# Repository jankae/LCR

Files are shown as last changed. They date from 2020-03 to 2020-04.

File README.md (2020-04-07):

# LCR Meter

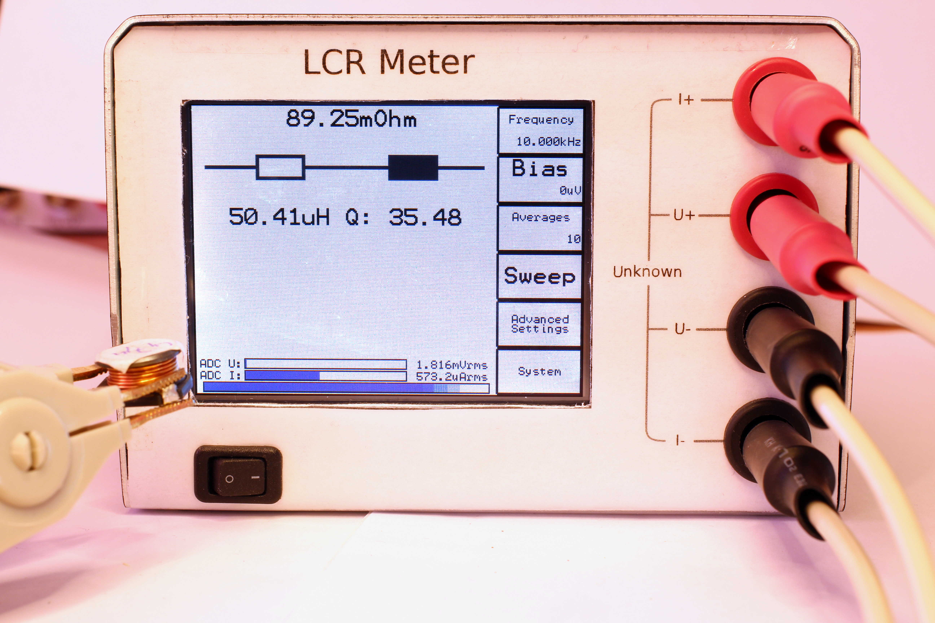
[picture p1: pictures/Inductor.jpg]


### Key specifications
* Measurement frequency: 100Hz-200kHz
* Usable impedance range: 20mOhm-1MOhm (measurements above and below this range are possible but due to very low ADC values, the reported phase will be quite noisy)
### Some useful features
* Optionally apply DC bias voltage up to 10V (measure effective capacitance of MLCCs)
* Autoranging
* Open/Short calibration (lead compensation)
* Fully configurable sweep, showing up to two parameters across frequency:
  * Impedance
  * Phase
  * Capacitance
  * Inductance
  * ESR
  * Quality factor
##### Example of a sweep, showing the self-resonant frequency of a capacitor at approximately 5.5kHz
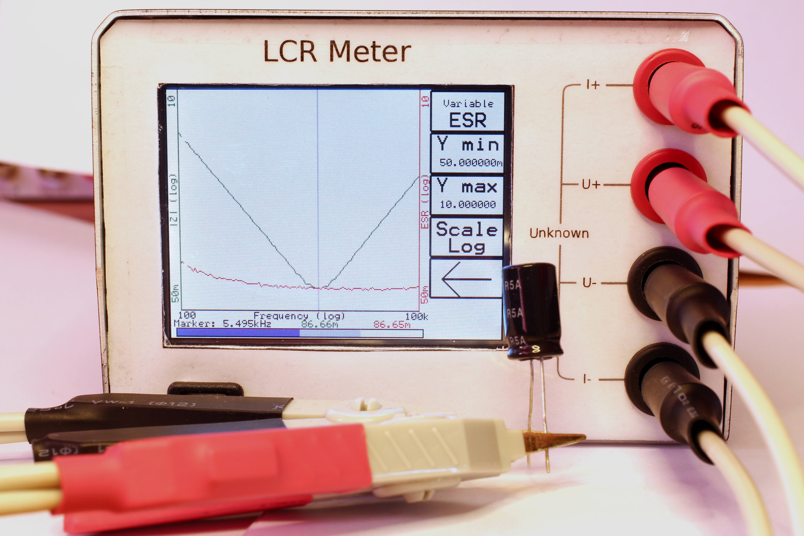
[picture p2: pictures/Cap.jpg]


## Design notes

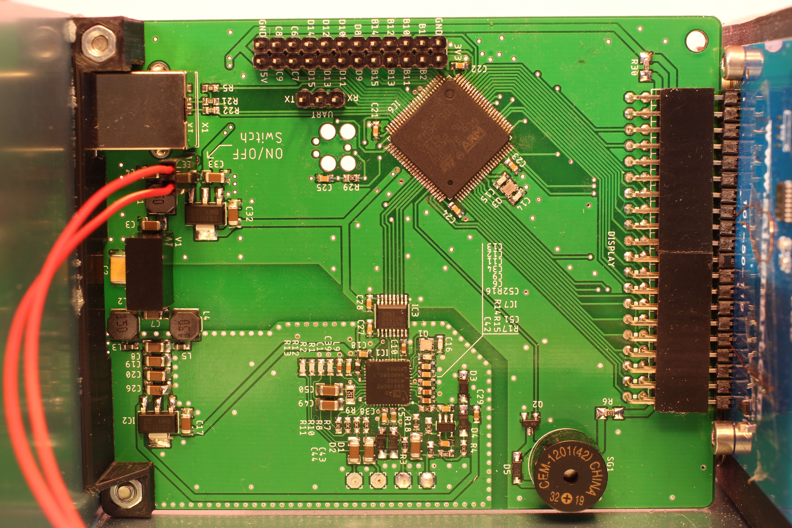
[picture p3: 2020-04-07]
pictures/PCB.jpg

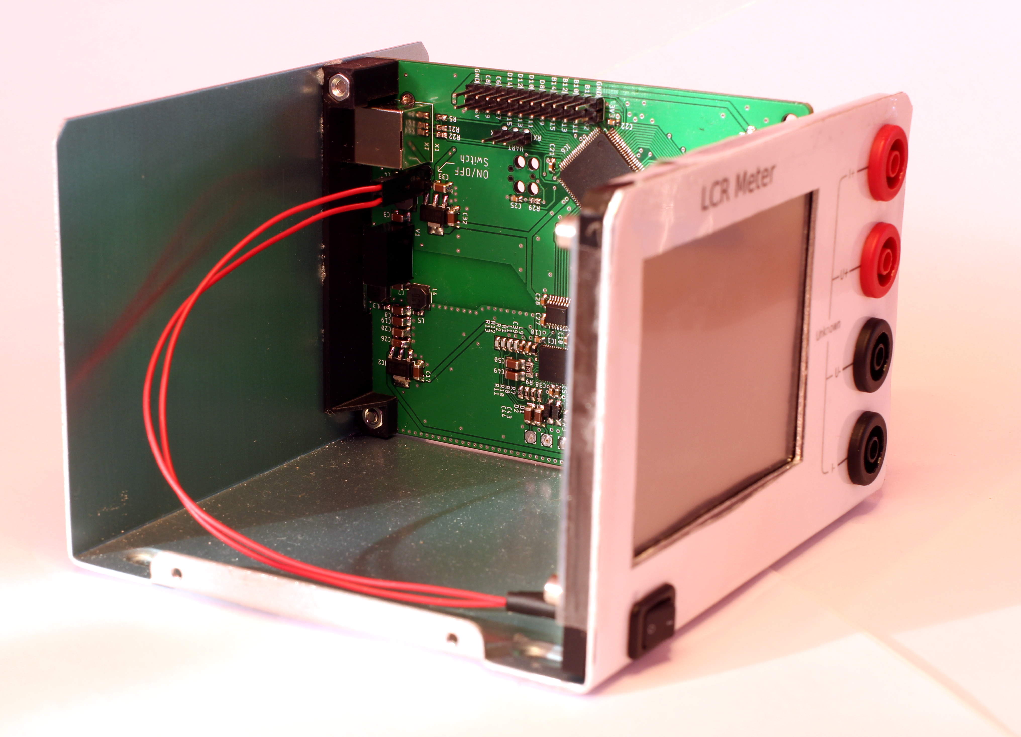
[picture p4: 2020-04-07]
pictures/LCR_left.jpg

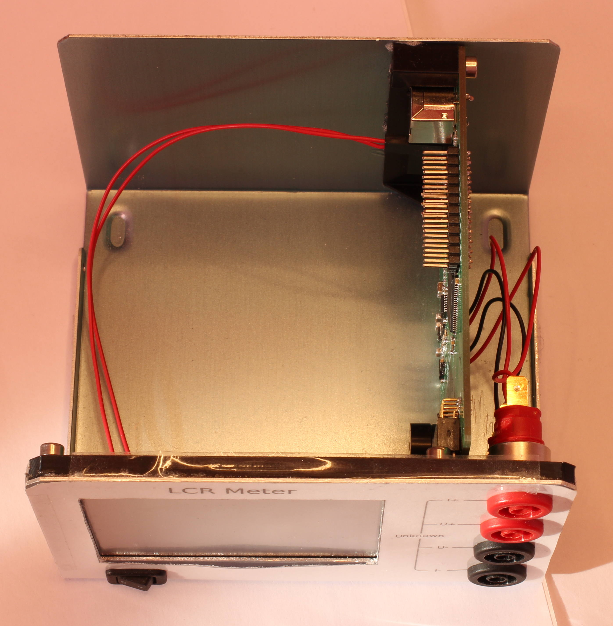
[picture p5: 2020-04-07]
pictures/Top.jpg

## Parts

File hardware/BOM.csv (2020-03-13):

Qty | Value | Device | Package | Parts | Mouser Link
4 |  | 2,54/1,1 | 2,54/1,1 | I+, I-, U+, U- | DNP
1 |  | PINHD-1X2 | 1X02 | JP1 | available
1 |  | PINHD-1X3 | 1X03 | UART | available
1 |  | PINHD-2X12 | 2X12 | JP2 | available
1 |  | TC2030-MCP | TC2030-MCP | J1 | DNP
2 | 10 | R-EU_R0603 | R0603 | R3, R18 | available
1 | 100 | R-EU_R0603 | R0603 | R17 | available
1 | 100k | R-EU_R0603 | R0603 | R4 | available
14 | 100n | C-EUC0603K | C0603K | C11, C18, C21, C22, C23, C24, C25, C27, C28, C34, C38, C39, C51, C52 | available
7 | 10k | R-EU_R0603 | R0603 | R7, R8, R10, R11, R14, R16, R29 | available
2 | 10p | C-EUC0603K | C0603K | C13, C16 | CC0603JRNPO9BN100
5 | 10u | C-EUC1206K | C1206K | C42, C43, C44, C49, C50 | TMK316BJ106ML-T
5 | 10u/16V | C-EUC1206K | C1206K | C3, C4, C17, C32, C33 | TMK316BJ106ML-T
5 | 10u/25V | C-EUC1206K | C1206K | C7, C8, C19, C20, C26 | TMK316BJ106ML-T
2 | 12p | C-EUC0603K | C0603K | C14, C15 | available
4 | 1M | R-EU_R0603 | R0603 | R1, R2, R12, R13 | available
1 | 1k 0.01% 2ppm | R-EU_M0805 | M0805 | R9 | RG2012L-102-L-T05
1 | 1k5 | R-EU_R0603 | R0603 | R5 | available
2 | 1u | C-EUC0603K | C0603K | C12, C29 | available
2 | 22 | R-EU_R0603 | R0603 | R21, R22 | available
2 | 27 | R-EU_R1206 | R1206 | R6, R30 | available
1 | 39k | R-EU_R0603 | R0603 | R15 | available
1 | 4148 | DIODE-SOD123 | SOD123 | D5 | MMSD4148T3G
4 | 470n | C-EUC0603K | C0603K | C1, C6, C9, C10 | CC0603ZRY5V7BB474
1 | 470p/3kV | C-EUC1812 | C1812 | C2 | 885352211001
1 | 4u7 | C-EUC0603K | C0603K | C5 | EMK107ABJ475MA-T
1 | AD5941 | AD5941 | QFN50P700X700X80-49T510N | IC1 | AD5941BCPZ-RL7
4 | BAS116 | DIODE-SOD123 | SOD123 | D1, D2, D3, D4 | BAS116GWJ
1 | BSS123 | BSS123 | SOT23 | Q2 | available
1 | CEM-1203(42) | F/QMBIII | F/QMBIII | SG1 | CEM-1201(42)
2 | FA-128 | FA-128 | FA-128 | Q1, Q3 | FA-128 32.0000MF10Z-AJ5 | FA-128 16.0000MF10Z-AC0
3 | Ferrite | INDUCTOR0603 | R0603 | L3, L5, L9 | available
1 | MINI-USB_SHIELD4P-85-32004-00X | MINI-USB_SHIELD4P-85-32004-00X | 85-32004-00X | X1 | SS-52300-001
1 | OPA237N | OPA237N | SOT23-5 | IC7 | OPA237NA/3K
1 | SAINSMART_TFT_3.2V | SAINSMART_TFT_3.2V | SAINSMART_ANGLED | DISPLAY | available
1 | SI8651EB-B-IU | SI8651EB-B-IU | SOP63P600X175-16N | IC3 | SI8651EB-B-IU
3 | SRN5020TA-100M | SRN5040 | SRN5040 | L1, L2, L4 | SRN5020TA-150M
1 | STM32F303VCT | STM32F303VCT | LQFP100 | IC6 | STM32F303VET6
1 | TBA-1 0512 | TME0505S | TME | V1 | TBA 1-0512
2 | VREG-TS1117CW-3V3 | VREG-TS1117CW-3V3 | SOT223 | IC2, IC9 | TS1117BCW33 RPG

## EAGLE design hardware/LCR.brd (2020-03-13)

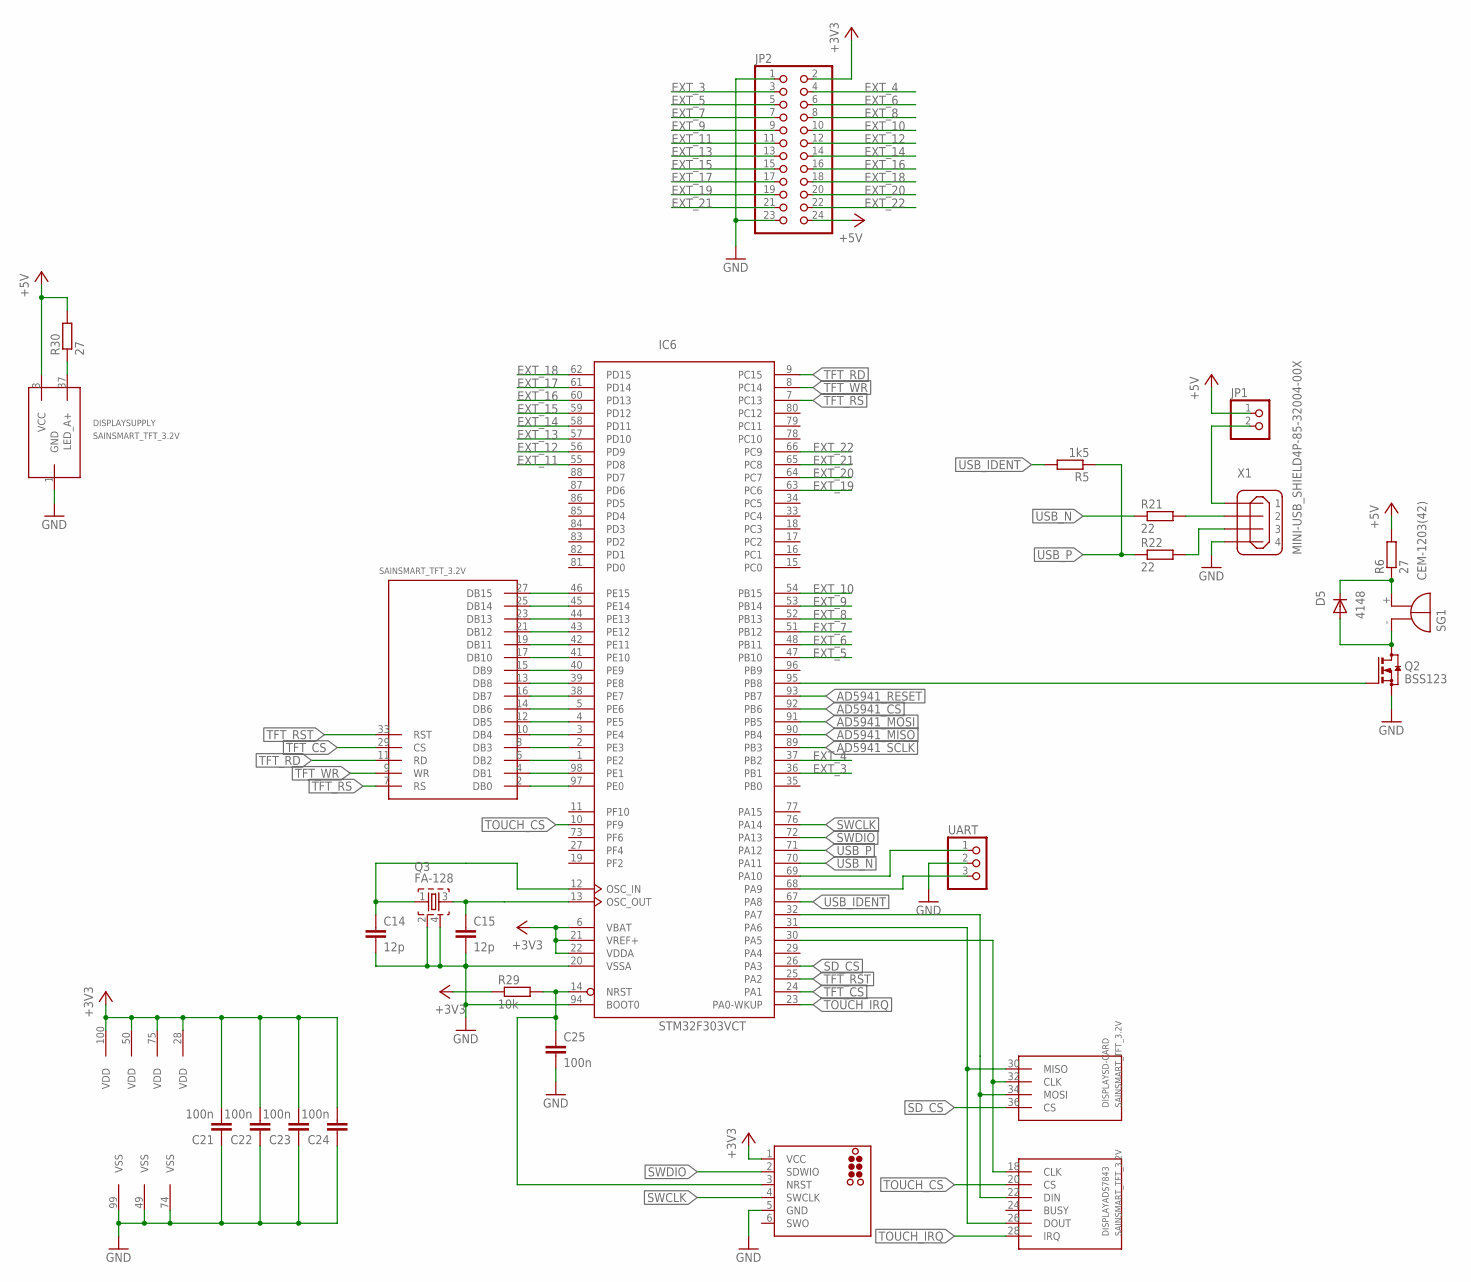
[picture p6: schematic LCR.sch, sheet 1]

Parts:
C14, C15: 12p; C0603K
C21, C22, C23, C24, C25: 100n; C0603K
D5: 4148; SOD123
DISPLAY: SAINSMART_TFT_3.2V; SAINSMART_ANGLED
IC6: STM32F303VCT; LQFP100
J1: TC2030-MCP
JP1: PINHD-1X2; 1X02
JP2: PINHD-2X12; 2X12
Q2: BSS123; SOT23
Q3: FA-128
R5: 1k5; R0603
R6, R30: 27; R1206
R21, R22: 22; R0603
R29: 10k; R0603
SG1: CEM-1203(42); F/QMBIII
UART: PINHD-1X3; 1X03
X1: MINI-USB_SHIELD4P-85-32004-00X; 85-32004-00X

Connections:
+3V3: C21.2, C22.2, C23.2, C24.2, IC6.6 (VBAT), IC6.21 (VREF+), IC6.22 (VDDA), IC6.28 (VDD), IC6.50 (VDD), IC6.75 (VDD), IC6.100 (VDD), J1.1 (VCC), JP2.2, R29.1; also elsewhere on the board
+5V: DISPLAY.3 (VCC), JP1.1, JP2.24, R6.2, R30.2; also elsewhere on the board
AD5941_CS: IC6.92 (PB6); also elsewhere on the board
AD5941_MISO: IC6.90 (PB4); also elsewhere on the board
AD5941_MOSI: IC6.91 (PB5); also elsewhere on the board
AD5941_RESET: IC6.93 (PB7); also elsewhere on the board
AD5941_SCLK: IC6.89 (PB3); also elsewhere on the board
EXT_3: IC6.36 (PB1), JP2.3
EXT_4: IC6.37 (PB2), JP2.4
EXT_5: IC6.47 (PB10), JP2.5
EXT_6: IC6.48 (PB11), JP2.6
EXT_7: IC6.51 (PB12), JP2.7
EXT_8: IC6.52 (PB13), JP2.8
EXT_9: IC6.53 (PB14), JP2.9
EXT_10: IC6.54 (PB15), JP2.10
EXT_11: IC6.55 (PD8), JP2.11
EXT_12: IC6.56 (PD9), JP2.12
EXT_13: IC6.57 (PD10), JP2.13
EXT_14: IC6.58 (PD11), JP2.14
EXT_15: IC6.59 (PD12), JP2.15
EXT_16: IC6.60 (PD13), JP2.16
EXT_17: IC6.61 (PD14), JP2.17
EXT_18: IC6.62 (PD15), JP2.18
EXT_19: IC6.63 (PC6), JP2.19
EXT_20: IC6.64 (PC7), JP2.20
EXT_21: IC6.65 (PC8), JP2.21
EXT_22: IC6.66 (PC9), JP2.22
GND: C14.2, C15.2, C21.1, C22.1, C23.1, C24.1, C25.2, DISPLAY.1 (GND), IC6.20 (VSSA), IC6.49 (VSS), IC6.74 (VSS), IC6.94 (BOOT0), IC6.99 (VSS), J1.5 (GND), JP2.1, JP2.23, Q2.2 (S), Q3.2, Q3.4, UART.2, X1.4; also elsewhere on the board
unnamed: IC6.95 (PB8), Q2.1 (G)
unnamed: DISPLAY.2 (DB0), IC6.97 (PE0)
unnamed: DISPLAY.4 (DB1), IC6.98 (PE1)
unnamed: DISPLAY.6 (DB2), IC6.1 (PE2)
unnamed: DISPLAY.8 (DB3), IC6.2 (PE3)
unnamed: DISPLAY.22 (DIN), DISPLAY.34 (MOSI), IC6.32 (PA7)
unnamed: DISPLAY.10 (DB4), IC6.3 (PE4)
unnamed: DISPLAY.12 (DB5), IC6.4 (PE5)
unnamed: DISPLAY.14 (DB6), IC6.5 (PE6)
unnamed: DISPLAY.16 (DB7), IC6.38 (PE7)
unnamed: DISPLAY.26 (DOUT), DISPLAY.30 (MISO), IC6.31 (PA6)
unnamed: DISPLAY.18 (CLK), DISPLAY.32 (CLK), IC6.30 (PA5)
unnamed: C14.1, IC6.12 (OSC_IN), Q3.1
unnamed: C15.1, IC6.13 (OSC_OUT), Q3.3
unnamed: R21.2, X1.2
unnamed: R22.2, X1.3
unnamed: C25.1, IC6.14 (NRST), J1.3 (NRST), R29.2
unnamed: DISPLAY.37 (LED_A+), R30.1
unnamed: DISPLAY.13 (DB8), IC6.39 (PE8)
unnamed: DISPLAY.15 (DB9), IC6.40 (PE9)
unnamed: DISPLAY.17 (DB10), IC6.41 (PE10)
unnamed: DISPLAY.19 (DB11), IC6.42 (PE11)
unnamed: JP1.2, X1.1
unnamed: D5.C, R6.1, SG1.+ (-)
unnamed: DISPLAY.21 (DB12), IC6.43 (PE12)
unnamed: DISPLAY.23 (DB13), IC6.44 (PE13)
unnamed: DISPLAY.25 (DB14), IC6.45 (PE14)
unnamed: DISPLAY.27 (DB15), IC6.46 (PE15)
unnamed: D5.A, Q2.3 (D), SG1.- (+)
RX: IC6.69 (PA10), UART.1
SD_CS: DISPLAY.36 (CS), IC6.26 (PA3)
SWCLK: IC6.76 (PA14), J1.4 (SWCLK)
SWDIO: IC6.72 (PA13), J1.2 (SDWIO)
TFT_CS: DISPLAY.29 (CS), IC6.24 (PA1)
TFT_RD: DISPLAY.11 (RD), IC6.9 (PC15)
TFT_RS: DISPLAY.7 (RS), IC6.7 (PC13)
TFT_RST: DISPLAY.33 (RST), IC6.25 (PA2)
TFT_WR: DISPLAY.9 (WR), IC6.8 (PC14)
TOUCH_CS: DISPLAY.20 (CS), IC6.10 (PF9)
TOUCH_IRQ: DISPLAY.28 (IRQ), IC6.23 (PA0-WKUP)
TX: IC6.68 (PA9), UART.3
USB_IDENT: IC6.67 (PA8), R5.2
USB_N: IC6.70 (PA11), R21.1
USB_P: IC6.71 (PA12), R5.1, R22.1

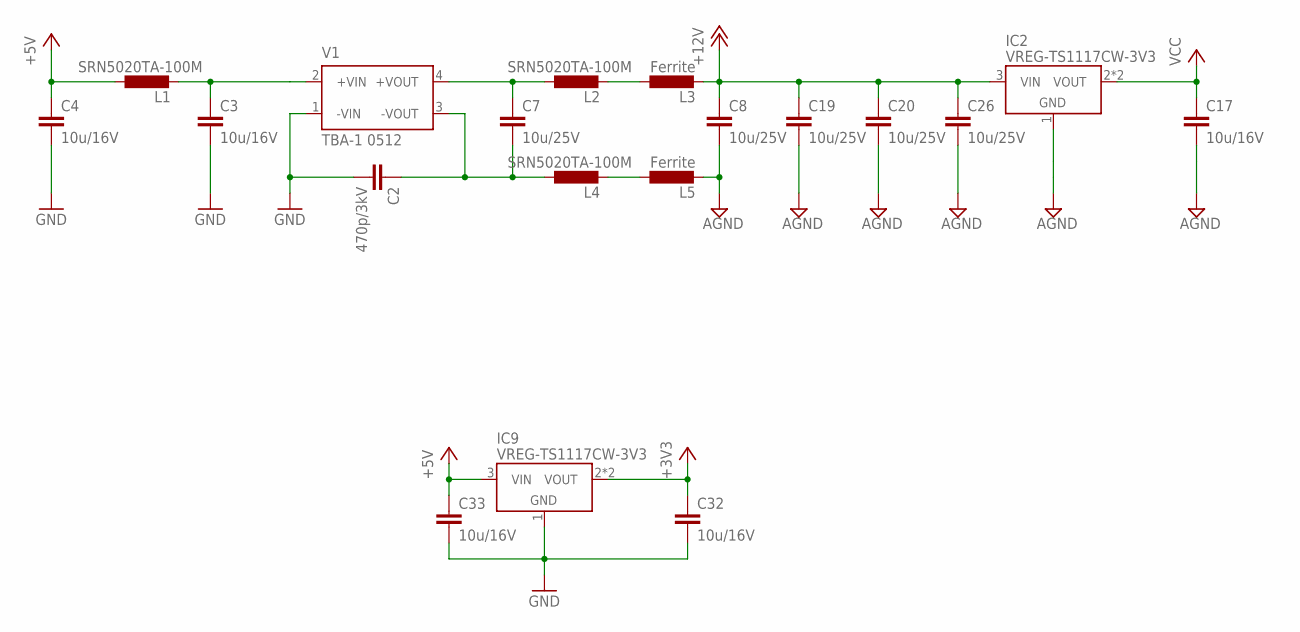
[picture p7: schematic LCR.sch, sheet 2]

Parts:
C2: 470p/3kV; C1812
C3, C4, C17, C32, C33: 10u/16V; C1206K
C7, C8, C19, C20, C26: 10u/25V; C1206K
IC2, IC9: VREG-TS1117CW-3V3; SOT223
L1, L2, L4: SRN5020TA-100M; SRN5040
L3, L5: Ferrite; R0603
V1: TBA-1 0512; TME

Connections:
+3V3: C32.1, IC9.2 (VOUT), IC9.4 (VOUT); also elsewhere on the board
+5V: C4.1, C33.1, IC9.3 (VIN), L1.P$1 (1); also elsewhere on the board
+12V: C8.1, C19.1, C20.1, C26.1, IC2.3 (VIN), L3.2; also elsewhere on the board
AGND: C8.2, C17.2, C19.2, C20.2, C26.2, IC2.1 (GND), L5.2; also elsewhere on the board
GND: C2.2, C3.2, C4.2, C32.2, C33.2, IC9.1 (GND), V1.1 (-VIN); also elsewhere on the board
unnamed: C3.1, L1.P$2 (2), V1.2 (+VIN)
unnamed: C7.1, L2.P$1 (1), V1.4 (+VOUT)
unnamed: C2.1, C7.2, L4.P$1 (1), V1.3 (-VOUT)
unnamed: L2.P$2 (2), L3.1
unnamed: L4.P$2 (2), L5.1
VCC: C17.1, IC2.2 (VOUT), IC2.4 (VOUT); also elsewhere on the board

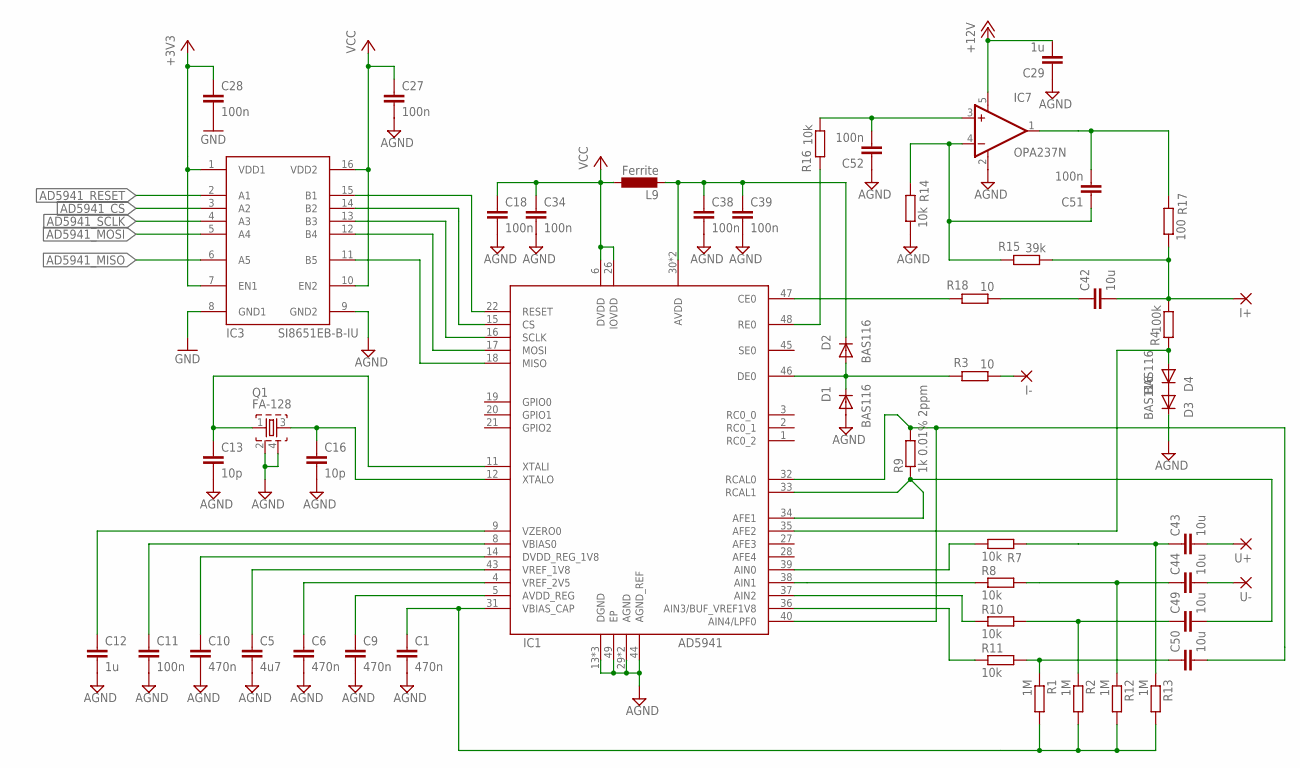
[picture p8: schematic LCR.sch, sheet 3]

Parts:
C1, C6, C9, C10: 470n; C0603K
C5: 4u7; C0603K
C11, C18, C27, C28, C34, C38, C39, C51, C52: 100n; C0603K
C12, C29: 1u; C0603K
C13, C16: 10p; C0603K
C42, C43, C44, C49, C50: 10u; C1206K
D1, D2, D3, D4: BAS116; SOD123
I+: 2,54/1,1
I-: 2,54/1,1
IC1: AD5941; QFN50P700X700X80-49T510N
IC3: SI8651EB-B-IU; SOP63P600X175-16N
IC7: OPA237N; SOT23-5
L9: Ferrite; R0603
Q1: FA-128
R1, R2, R12, R13: 1M; R0603
R3, R18: 10; R0603
R4: 100k; R0603
R7, R8, R10, R11, R14, R16: 10k; R0603
R9: 1k 0.01% 2ppm; M0805
R15: 39k; R0603
R17: 100; R0603
U+: 2,54/1,1
U-: 2,54/1,1

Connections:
+3V3: C28.1, IC3.1 (VDD1), IC3.7 (EN1); also elsewhere on the board
+12V: C29.2, IC7.5 (V+); also elsewhere on the board
AD5941_CS: IC3.3 (A2); also elsewhere on the board
AD5941_MISO: IC3.6 (A5); also elsewhere on the board
AD5941_MOSI: IC3.5 (A4); also elsewhere on the board
AD5941_RESET: IC3.2 (A1); also elsewhere on the board
AD5941_SCLK: IC3.4 (A3); also elsewhere on the board
AGND: C1.2, C5.2, C6.2, C9.2, C10.2, C11.2, C12.2, C13.2, C16.2, C18.2, C27.2, C29.1, C34.2, C38.2, C39.2, C52.1, D1.A, D3.C, IC1.13 (DGND), IC1.23 (DGND), IC1.25 (DGND), IC1.29 (AGND), IC1.42 (AGND), IC1.44 (AGND_REF), IC1.49 (EP), IC3.9 (GND2), IC7.2 (V-), Q1.2, Q1.4, R14.1; also elsewhere on the board
GND: C28.2, IC3.8 (GND1); also elsewhere on the board
I+: C42.2, I+.1, R4.1, R15.1, R17.1
I-: I-.1, R3.1
unnamed: C1.1, IC1.31 (VBIAS_CAP), R1.2, R2.2, R12.2, R13.2
unnamed: C6.1, IC1.4 (VREF_2V5)
unnamed: C5.1, IC1.43 (VREF_1V8)
unnamed: C9.1, IC1.5 (AVDD_REG)
unnamed: C10.1, IC1.14 (DVDD_REG_1V8)
unnamed: C11.1, IC1.8 (VBIAS0)
unnamed: C12.1, IC1.9 (VZERO0)
unnamed: C16.1, IC1.12 (XTALO), Q1.3
unnamed: C13.1, IC1.11 (XTALI), Q1.1
unnamed: IC1.17 (MOSI), IC3.12 (B4)
unnamed: C42.1, R18.1
unnamed: IC1.22 (RESET), IC3.15 (B1)
unnamed: IC1.15 (CS), IC3.14 (B2)
unnamed: IC1.16 (SCLK), IC3.13 (B3)
unnamed: IC1.18 (MISO), IC3.11 (B5)
unnamed: C38.1, C39.1, D2.C, IC1.30 (AVDD), IC1.41 (AVDD), L9.2
unnamed: IC1.47 (CE0), R18.2
unnamed: IC1.39 (AIN0), R7.1
unnamed: IC1.38 (AIN1), R8.1
unnamed: C44.1, R8.2, R12.1
unnamed: C43.1, R7.2, R13.1
unnamed: C49.2, IC1.33 (RCAL1), IC1.34 (AFE1), R9.1
unnamed: IC1.37 (AIN2), R10.1
unnamed: IC1.36 (AIN3/BUF_VREF1V8), R11.1
unnamed: C50.1, R1.1, R11.2
unnamed: C49.1, R2.1, R10.2
unnamed: IC1.48 (RE0), R16.2
unnamed: C52.2, IC7.3 (+IN), R16.1
unnamed: C51.1, IC7.4 (-IN), R14.2, R15.2
unnamed: C51.2, IC7.1 (OUT), R17.2
unnamed: D1.C, D2.A, IC1.46 (DE0), R3.2
unnamed: D4.A, IC1.35 (AFE2), R4.2
unnamed: D3.A, D4.C
unnamed: C50.2, IC1.32 (RCAL0), IC1.40 (AIN4/LPF0), R9.2
U+: C43.2, U+.1
U-: C44.2, U-.1
VCC: C18.1, C27.1, C34.1, IC1.6 (DVDD), IC1.26 (IOVDD), IC3.10 (EN2), IC3.16 (VDD2), L9.1; also elsewhere on the board

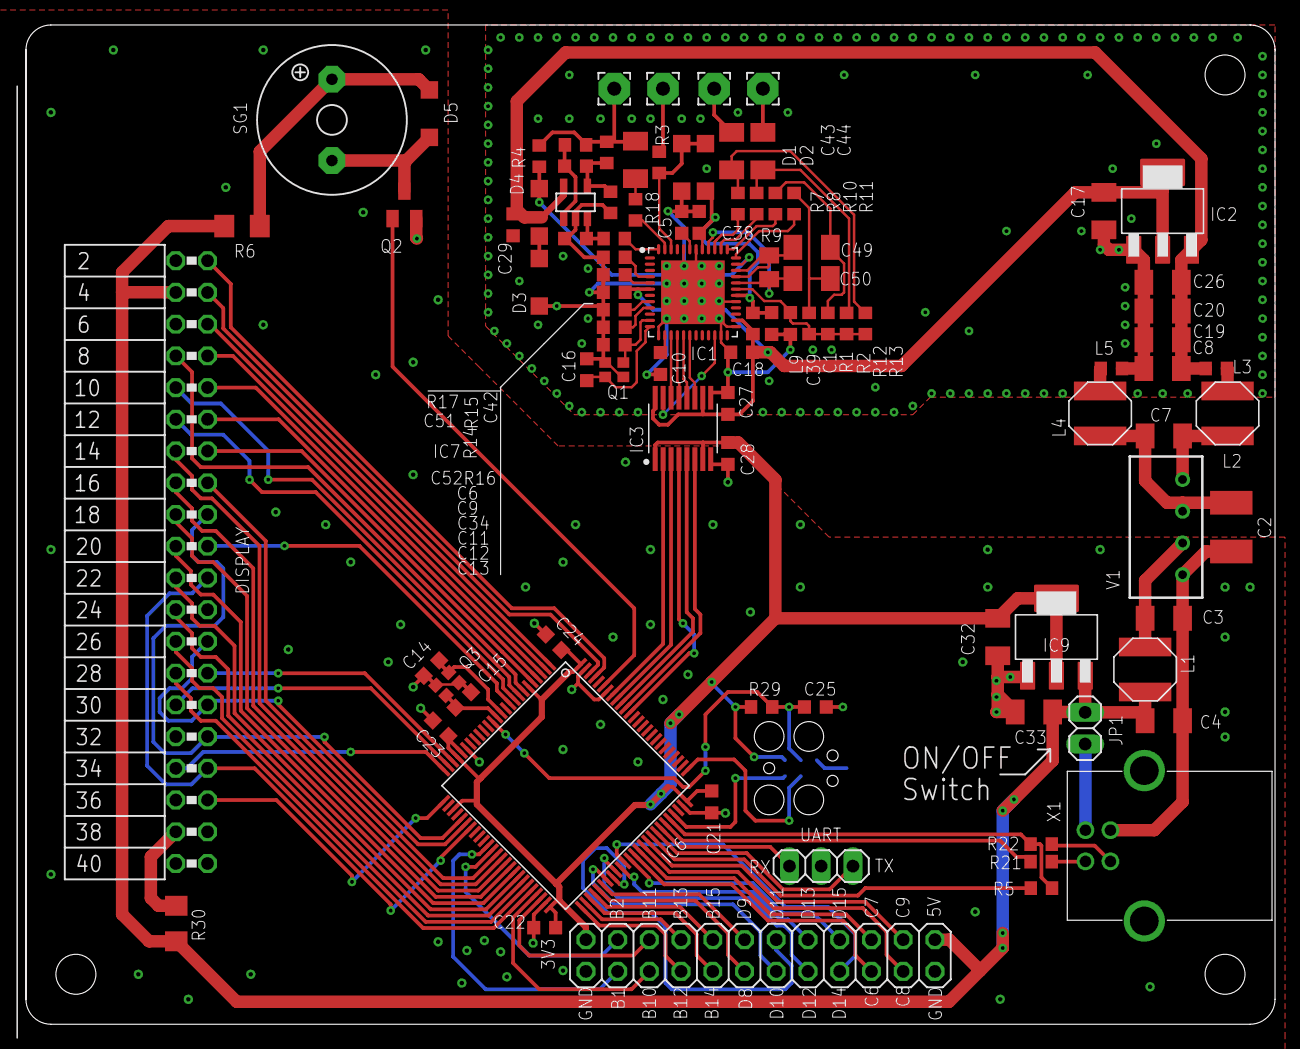
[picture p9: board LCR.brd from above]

Board: 2 copper layers, 100.0 x 80.0 mm, 95 parts (1 on the bottom side), 118 nets.

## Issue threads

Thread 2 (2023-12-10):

R21 and R22

wocard2, 2023-12-10:
The STM32F303xC datasheet says:

No external termination series resistors are required on USB_DP (D+) and USB_DM (D-), the matching impedance is already included in the embedded driver.

In consequence, R21 and R22 should be populated with 0 Ω resistors.

jankae, 2023-12-10:
Ah, thanks for the info :) I probably didn't read the datasheet that closely and simply replicated what I have used in other projects for USB. There were never any issues with the 22R resistors but of course the correct solution according to the datasheet would be using 0R resistors.

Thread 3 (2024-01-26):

Measurement results off by a factor of 1.5 after calibration

wocard2, 2024-01-26:
In the schematic, reference resistor R9 has a value of 1 kΩ, in the source code (lines 587 and 588 of Frontend.cpp), a value of 1.5 kΩ is used for the reference resistor.

wocard2, 2024-01-26:
Calibration resistor, not reference resistor. Sorry.

jankae, 2024-01-26:
This is likely just a result of part availability when I built my device. My guess is that I wanted to use a 1 kΩ but it wasn't available when I ordered the parts, so I changed to 1.5 kΩ and forgot to adjust the schematic

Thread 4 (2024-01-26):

Vʀᴇғɪɴᴛ of STM32F303

wocard2, 2024-01-26:
Start.cpp says

	constexpr float ReferenceTypical = 1.2f;

but the typical value for the Internal reference voltage of the STM32F303 is 1.23 V according to the datasheet. Harmless.

jankae, 2024-01-26:
You are right. Maybe I mistakenly used the min value? If you want, you can create a PR for this (and the other small issues you found), I'd be glad to merge that

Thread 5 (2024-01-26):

Vbias0 of AD5941

wocard2, 2024-01-26:
Fontend.cpp says

static constexpr uint32_t referenceVoltage = 1100000;

I think this should be Vbias0 (1.11 V, ie, 1110000) rather than the reference voltage for the DAC (1.1 V, ie, 1100000). Probably doesn't hurt and gets fixed by calibration anyway.

jankae, 2024-01-26:
Yes, that value should have one more 1. If I remember correctly, this value doesn't affect the measurement result at all but it responsible for setting the correct DC bias for the DUT. I guess that with the current code, the DC bias has an offset of 10 mV

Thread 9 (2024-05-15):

DDS filter file shows format error on latest lispice software

wrench1997, 2024-05-15:
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

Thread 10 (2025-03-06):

Unable to compile

holkono, 2025-03-06:
Hi, I've been trying to compile this for several days now but can't get it compile.

I have tried several versions of STM32cubeIDE, the old system workbench and IAR trail versions but can't get nothing to work.

Do you have some compile instructions or at this point I'd be happy with a precompiled binary.

Thanks.

jankae, 2025-03-06:
Okay, lets see. First a word of warning: this is a one-off project which I did quite a while ago and may not remember all the details. The LCR still works and I occasionally use it, but I do not intend to maintain this project very well. The repo is more or less just a backup and minimal documentation for me.

Checking out the code and starting STM32CubeIDE 1.8.0 (yes, I am still on that old version) got me a couple of compilation errors:

> error: partial specialization 'struct {anonymous}::pmf_cast<R (*)(F, A ...), C, p>' is not more specialized than [-fpermissive]

Looks like the newer compiler version does not like the template magic for function pointer casts (and I am not proficient enough in C++ templates to improve the code if that is possible).

Adding `-fpermissive` to the C++ compiler as suggested by that error message gets me a step further.
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

I am now stuck with a linker error:

> Error: Cannot find the specified linker script. Check the linker settings in the build configuration.

Checking the linker script path reveals a strange filename:
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

The actual linker script is called `STM32F303VETx_FLASH.ld`. No idea why the IDE has this set to the wrong (non-existing) file.

Fixing the linker file setting, we can move on to the next error:

> ../Drivers/Board/Display/display.c:103: undefined reference to \`selectRegister'
../Drivers/Board/Display/display.c:129: undefined reference to \`setYStartStop'
[...] more undefined references

All these errors complain about functions defined in [display.c](https://github.com/jankae/LCR/blob/master/software/LCRMeter/Drivers/Board/Display/display.c), specifically all function with the keyword `inline`. A quick [google search](https://stackoverflow.com/questions/19068705/undefined-reference-when-calling-inline-function) seems to indicate that the compiler does not like the `inline` keyword on its own (just in combination with `static`). Again, not sure why this worked at some point.

But the inline keyword is just a suggestion to the compiler anyway as far as I know. It is not really required, the optimization will take care of that.
So I replaced all `inline` occurrences with `static` in that file. And:

> arm-none-eabi-size   LCRMeter.elf
   text	   data	    bss	    dec	    hex	filename
 153664	    568	  59192	 213424	  341b0	LCRMeter.elf
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

Looks like it finally worked. No idea whether that software will actually run, but here is the binary:
[LCR.zip](https://github.com/user-attachments/files/19107241/LCR.zip)

jankae, 2025-03-06:
Looks like #8 also took care of compilation errors along with other improvements. You may be better off just using that fork.

holkono, 2025-03-06:
Wow that was fast!

Many many thanks for your instructions! I've been banging my head against the wall but my programming experience is more or less none existing and therefore don't have the skills and knowledge to understand the logs.

Thanks!

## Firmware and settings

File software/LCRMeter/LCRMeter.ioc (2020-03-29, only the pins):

Mcu.UserName=STM32F303VETx
PA0.GPIO_Label=TOUCH_IRQ
PA0.Signal=GPIO_Input
PA1.GPIO_Label=DISP_CS
PA1.Signal=GPIO_Output
PA10.Signal=USART1_RX
PA11.Signal=USB_DM
PA12.Signal=USB_DP
PA13.Signal=SYS_JTMS-SWDIO
PA14.Signal=SYS_JTCK-SWCLK
PA2.GPIO_Label=DISP_RST
PA2.Signal=GPIO_Output
PA3.GPIO_Label=SD_CS
PA3.Signal=GPIO_Output
PA5.Signal=SPI1_SCK
PA6.Signal=SPI1_MISO
PA7.Signal=SPI1_MOSI
PA8.GPIO_Label=USB_IDENT
PA8.Signal=GPIO_Output
PA9.Signal=USART1_TX
PB3.Signal=SPI3_SCK
PB4.Signal=SPI3_MISO
PB5.Signal=SPI3_MOSI
PB6.GPIO_Label=AD5941_CS
PB6.Signal=GPIO_Output
PB7.GPIO_Label=AD5941_RESET
PB7.Signal=GPIO_Output
PB8.GPIO_Label=SOUND_INT
PB8.Signal=S_TIM8_CH2
PC13.GPIO_Label=DISP_RS
PC13.Signal=GPIO_Output
PC14-OSC32_IN.GPIO_Label=DISP_WR
PC14-OSC32_IN.Signal=GPIO_Output
PC15-OSC32_OUT.GPIO_Label=DISP_RD
PC15-OSC32_OUT.Signal=GPIO_Output
PE0.GPIO_Label=DISP_IO0
PE0.Signal=GPIO_Output
PE1.GPIO_Label=DISP_IO1
PE1.Signal=GPIO_Output
PE10.GPIO_Label=DISP_IO10
PE10.Signal=GPIO_Output
PE11.GPIO_Label=DISP_IO11
PE11.Signal=GPIO_Output
PE12.GPIO_Label=DISP_IO12
PE12.Signal=GPIO_Output
PE13.GPIO_Label=DISP_IO13
PE13.Signal=GPIO_Output
PE14.GPIO_Label=DISP_IO14
PE14.Signal=GPIO_Output
PE15.GPIO_Label=DISP_IO15
PE15.Signal=GPIO_Output
PE2.GPIO_Label=DISP_IO2
PE2.Signal=GPIO_Output
PE3.GPIO_Label=DISP_IO3
PE3.Signal=GPIO_Output
PE4.GPIO_Label=DISP_IO4
PE4.Signal=GPIO_Output
PE5.GPIO_Label=DISP_IO5
PE5.Signal=GPIO_Output
PE6.GPIO_Label=DISP_IO6
PE6.Signal=GPIO_Output
PE7.GPIO_Label=DISP_IO7
PE7.Signal=GPIO_Output
PE8.GPIO_Label=DISP_IO8
PE8.Signal=GPIO_Output
PE9.GPIO_Label=DISP_IO9
PE9.Signal=GPIO_Output
PF0-OSC_IN.Signal=RCC_OSC_IN
PF1-OSC_OUT.Signal=RCC_OSC_OUT
PF9.GPIO_Label=TOUCH_CS
PF9.Signal=GPIO_Output

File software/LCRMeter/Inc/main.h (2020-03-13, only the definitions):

#define DISP_IO2_Pin GPIO_PIN_2
#define DISP_IO2_GPIO_Port GPIOE
#define DISP_IO3_Pin GPIO_PIN_3
#define DISP_IO3_GPIO_Port GPIOE
#define DISP_IO4_Pin GPIO_PIN_4
#define DISP_IO4_GPIO_Port GPIOE
#define DISP_IO5_Pin GPIO_PIN_5
#define DISP_IO5_GPIO_Port GPIOE
#define DISP_IO6_Pin GPIO_PIN_6
#define DISP_IO6_GPIO_Port GPIOE
#define DISP_RS_Pin GPIO_PIN_13
#define DISP_RS_GPIO_Port GPIOC
#define DISP_WR_Pin GPIO_PIN_14
#define DISP_WR_GPIO_Port GPIOC
#define DISP_RD_Pin GPIO_PIN_15
#define DISP_RD_GPIO_Port GPIOC
#define TOUCH_CS_Pin GPIO_PIN_9
#define TOUCH_CS_GPIO_Port GPIOF
#define TOUCH_IRQ_Pin GPIO_PIN_0
#define TOUCH_IRQ_GPIO_Port GPIOA
#define DISP_CS_Pin GPIO_PIN_1
#define DISP_CS_GPIO_Port GPIOA
#define DISP_RST_Pin GPIO_PIN_2
#define DISP_RST_GPIO_Port GPIOA
#define SD_CS_Pin GPIO_PIN_3
#define SD_CS_GPIO_Port GPIOA
#define DISP_IO7_Pin GPIO_PIN_7
#define DISP_IO7_GPIO_Port GPIOE
#define DISP_IO8_Pin GPIO_PIN_8
#define DISP_IO8_GPIO_Port GPIOE
#define DISP_IO9_Pin GPIO_PIN_9
#define DISP_IO9_GPIO_Port GPIOE
#define DISP_IO10_Pin GPIO_PIN_10
#define DISP_IO10_GPIO_Port GPIOE
#define DISP_IO11_Pin GPIO_PIN_11
#define DISP_IO11_GPIO_Port GPIOE
#define DISP_IO12_Pin GPIO_PIN_12
#define DISP_IO12_GPIO_Port GPIOE
#define DISP_IO13_Pin GPIO_PIN_13
#define DISP_IO13_GPIO_Port GPIOE
#define DISP_IO14_Pin GPIO_PIN_14
#define DISP_IO14_GPIO_Port GPIOE
#define DISP_IO15_Pin GPIO_PIN_15
#define DISP_IO15_GPIO_Port GPIOE
#define USB_IDENT_Pin GPIO_PIN_8
#define USB_IDENT_GPIO_Port GPIOA
#define AD5941_CS_Pin GPIO_PIN_6
#define AD5941_CS_GPIO_Port GPIOB
#define AD5941_RESET_Pin GPIO_PIN_7
#define AD5941_RESET_GPIO_Port GPIOB
#define SOUND_INT_Pin GPIO_PIN_8
#define SOUND_INT_GPIO_Port GPIOB
#define DISP_IO0_Pin GPIO_PIN_0
#define DISP_IO0_GPIO_Port GPIOE
#define DISP_IO1_Pin GPIO_PIN_1
#define DISP_IO1_GPIO_Port GPIOE

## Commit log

2019-01-19 Software for breadboard test
    [New_configuration.cfg]
2020-03-08 Beginning of new design based on AD5941
    [ADCSample.csv, frontend.brd, frontend.sch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]
2020-03-13 Cleanup of old HW/code and created OS structure + GUI code
    [BOM.csv, BOM.ods, LCR.brd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]
2020-03-26 Bugfixes Display and touch driver
    [Frontend.cpp, LCR.cpp, LCRMeter.ioc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]
2020-03-27 Bugfixes AD5941 clock system and excitation signal generation
    [Frontend.cpp, LCR.cpp, ad5940.c]
2020-03-28 Autoranging, ADC overload detection, excitation amplitude corrected
    [Frontend.cpp, HardwareLimits.hpp, LCR.cpp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]
2020-03-29 Low/high frequency settings fixed, acquisition bar and faster autoranging
    [Frontend.cpp, HardwareLimits.hpp, LCR.cpp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]
2020-04-07 Marker readout in sweep, sweep acquition fix when wrapping around
    [Frontend.cpp, LCR.cpp, Start.cpp]

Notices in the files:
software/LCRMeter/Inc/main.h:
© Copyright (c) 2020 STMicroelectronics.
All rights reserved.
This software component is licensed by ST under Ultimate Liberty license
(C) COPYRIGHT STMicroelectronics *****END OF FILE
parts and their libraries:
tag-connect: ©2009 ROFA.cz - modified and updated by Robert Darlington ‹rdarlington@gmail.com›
